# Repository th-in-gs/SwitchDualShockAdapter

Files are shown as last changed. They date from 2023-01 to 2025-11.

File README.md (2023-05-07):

# SwitchDualShockAdapter

A work-in-progress Dual Shock to Switch controller adapter using an ATMega8A and V-USB.

I'm documenting the project on my blog, https://www.blog.montgomerie.net/tags/switch-dual-shock-adapter-series/.

# Acknowledgements

This project is designed to be compiled by the PlatformIO system (https://platformio.org).

This project depends upon Objective Development's V-USB (https://www.obdev.at/vusb/) - see the `v-usb` directory.

This project depends upon the MiniCore implementation of the Arduino framework (https://github.com/MCUdude/MiniCore).

# Copyright

Copyright 2023 James Montgomerie.

This project is distributed under the terms of the GNU General Public License (see LICENSE.txt), in order to comply with the licensing conditions of its dependencies (see 'Acknowledgements').

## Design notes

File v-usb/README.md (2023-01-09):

What is V-USB?
==============
V-USB is a firmware-only USB driver for Atmel's AVR microcontrollers.
For more information please visit <http://www.obdev.at/vusb/>.

What is in this Repository?
===========================
This repository contains the source code of the driver (in the usbdrv
subdirectory), examples (in the examples) subdirectory and other things
you might need when you design a device using V-USB.

When you check out this repository, the resulting directory is *not* equivalent
to the source code package which can be downloaded at
<http://www.obdev.at/vusb/>. Some files in the source code package are generated
by scripts when the package is created. On the other hand, the scripts which
generate source files and the package are not contained in the package itself.

If you want to know more about the files and directories, see the file
Readme.txt in the top level directory.

How do I Add the Driver to My Project?
======================================
Simply copy the entire usbdrv subdirectory into your project's firmware
source code directory. Then edit the firmware's Makefile and add the following
object files to your binary:

    usbdrv/usbdrv.o
    usbdrv/usbdrvasm.o
    usbdrv/oddebug.o

Then make sure that your Makefile contains rules to convert *.S and *.c to
object files. See the Makefiles in the examples subdirectory for an
inspiration.

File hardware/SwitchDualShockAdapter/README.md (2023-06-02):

KiCad project, with schematic and PCB layout.
The PCB should be run through the "Round Tracks" plugin before production.
The components associated with the two LEDs are optional, as are one of either the USB header or USB-C port

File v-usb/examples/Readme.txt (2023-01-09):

This is the Readme file for the directory "examples" of V-USB, a firmware-
only USB driver for AVR microcontrollers.

WHAT IS IN THIS DIRECTORY?
==========================
This directory contains examples which are mostly for educational purposes.
Examples can be device firmware only, host software only or both. Here is
a summary:

custom-class
  A custom class device with host software based on libusb. It demonstrates
  the straight forward way of sending small amounts of data to a device and
  receiving data from the device. It does NOT demonstrate how to send large
  amounts of data to the device or how to receive data generated on the fly
  by the device (how to use usbFunctionWrite() and usbFunctionRead()). See
  the hid-data example for how usbFunctionWrite() and usbFunctionRead() are
  used.

hid-custom-rq
  This example implements the same functionality as the custom-class example
  above, but declares the device as HID. This prevents the "give me a driver
  CD" dialog on Windows. The device can still be controlled with libusb as in
  the previous example (on Windows, the filter version of libusb-win32 must
  be installed). In addition to the features presented in custom-class, this
  example demonstrates how a HID class device is defined.

hid-mouse
  This example implements a mouse device. No host driver is required since
  today's operating systems have drivers for USB mice built-in. It
  demonstrates how a real-world HID class device is implemented and how
  interrupt-in endpoints are used.

hid-data
  This example demonstrates how the HID class can be misused to transfer
  arbitrary data over HID feature reports. This technique is of great value
  on Windows because no driver DLLs are needed (the hid-custom-rq example
  still requires the libusb-win32 DLL, although it may be in the program's
  directory). The host side application requires no installation, it can
  even be started directly from a CD. This example also demonstrates how
  to transfer data using usbFunctionWrite() and usbFunctionRead().

usbtool
  This is a general purpose development and debugging tool for USB devices.
  You can use it during development of your device to test various requests
  without special test programs. But it is also an example how all the
  libusb API functions are used.

More information about each example can be found in the Readme file in the
respective directory.

Hardware dependencies of AVR code has been kept at a minimum. All examples
should work on any AVR chip which has enough resources to run the driver.
Makefile and usbconfig.h have been configured for the metaboard hardware (see
http://www.obdev.at/goto.php?t=metaboard for details). Edit the target
device, fuse values, clock rate and programmer in Makefile and the I/O pins
dedicated to USB in usbconfig.h.

WHAT IS NOT DEMONSTRATED IN THESE EXAMPLES?
===========================================
These examples show only the most basic functionality. More elaborate
examples and real world applications showing more features of the driver are
available at http://www.obdev.at/vusb/projects.html. Most of these
features are described in our documentation wiki at
http://www.obdev.at/goto.php?t=vusb-wiki.

To mention just a few:

Using RC oscillator for system clock
  The 12.8 MHz and 16.5 MHz modules of V-USB have been designed to cope
  with clock rate deviations up to 1%. This allows an RC oscillator to be
  used. Since the AVR's RC oscillator has a factory precision of only 10%,
  it must be calibrated to an external reference. The EasyLogger example
  shows how this can be done.

Dynamically generated descriptors
  Sometimes you want to implement different typtes of USB device depending
  on a jumper or other condition. V-USB has a very flexible interface for
  providing USB descriptors. See AVR-Doper for how to provide descriptors
  at runtime.

Virtual COM port
  Some people prefer a virtual serial interface to communicate with their
  device. We strongly discourage this method because it does things
  forbidden by the USB specification. If you still want to go this route,
  see AVR-CDC.

Implementing suspend mode
  V-USB does not implement suspend mode. This means that the device does
  not reduce power consumption when the host goes into sleep mode. Device
  firmware is free to implement suspend mode, though. See USB2LPT for an
  example.

The projects mentioned above can best be found on

    http://www.obdev.at/vusb/prjall.html

where all projects are listed.

----------------------------------------------------------------------------
(c) 2009 by OBJECTIVE DEVELOPMENT Software GmbH.
http://www.obdev.at/

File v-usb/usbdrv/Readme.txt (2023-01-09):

This is the Readme file to Objective Development's firmware-only USB driver
for Atmel AVR microcontrollers. For more information please visit
http://www.obdev.at/vusb/

This directory contains the USB firmware only. Copy it as-is to your own
project and add all .c and .S files to your project (these files are marked
with an asterisk in the list below). Then copy usbconfig-prototype.h as
usbconfig.h to your project and edit it according to your configuration.

TECHNICAL DOCUMENTATION
=======================
The technical documentation (API) for the firmware driver is contained in the
file "usbdrv.h". Please read all of it carefully! Configuration options are
documented in "usbconfig-prototype.h".

The driver consists of the following files:
  Readme.txt ............. The file you are currently reading.
  Changelog.txt .......... Release notes for all versions of the driver.
  usbdrv.h ............... Driver interface definitions and technical docs.
* usbdrv.c ............... High level language part of the driver. Link this
                           module to your code!
* usbdrvasm.S ............ Assembler part of the driver. This module is mostly
                           a stub and includes one of the usbdrvasm*.S files
                           depending on processor clock. Link this module to
                           your code!
  usbdrvasm*.inc ......... Assembler routines for particular clock frequencies.
                           Included by usbdrvasm.S, don't link it directly!
  asmcommon.inc .......... Common assembler routines. Included by
                           usbdrvasm*.inc, don't link it directly!
  usbconfig-prototype.h .. Prototype for your own usbdrv.h file.
* oddebug.c .............. Debug functions. Only used when DEBUG_LEVEL is
                           defined to a value greater than 0. Link this module
                           to your code!
  oddebug.h .............. Interface definitions of the debug module.
  usbportability.h ....... Header with compiler-dependent stuff.
  usbdrvasm.asm .......... Compatibility stub for IAR-C-compiler. Use this
                           module instead of usbdrvasm.S when you assembler
                           with IAR's tools.
  License.txt ............ Open Source license for this driver.
  CommercialLicense.txt .. Optional commercial license for this driver.
  USB-ID-FAQ.txt ......... General infos about USB Product- and Vendor-IDs.
  USB-IDs-for-free.txt ... List and terms of use for free shared PIDs.

(*) ... These files should be linked to your project.

CPU CORE CLOCK FREQUENCY
========================
We supply assembler modules for clock frequencies of 12 MHz, 12.8 MHz, 15 MHz,
16 MHz, 16.5 MHz 18 MHz and 20 MHz. Other clock rates are not supported. The
actual clock rate must be configured in usbconfig.h.

12 MHz Clock
This is the traditional clock rate of V-USB because it's the lowest clock
rate where the timing constraints of the USB spec can be met.

15 MHz Clock
Similar to 12 MHz, but some NOPs inserted. On the other hand, the higher clock
rate allows for some loops which make the resulting code size somewhat smaller
than the 12 MHz version.

16 MHz Clock
This clock rate has been added for users of the Arduino board and other
ready-made boards which come with a fixed 16 MHz crystal. It's also an option
if you need the slightly higher clock rate for performance reasons. Since
16 MHz is not divisible by the USB low speed bit clock of 1.5 MHz, the code
is somewhat tricky and has to insert a leap cycle every third byte.

12.8 MHz and 16.5 MHz Clock
The assembler modules for these clock rates differ from the other modules
because they have been built for an RC oscillator with only 1% precision. The
receiver code inserts leap cycles to compensate for clock deviations. 1% is
also the precision which can be achieved by calibrating the internal RC
oscillator of the AVR. Please note that only AVRs with internal 64 MHz PLL
oscillator can reach 16.5 MHz with the RC oscillator. This includes the very
popular ATTiny25, ATTiny45, ATTiny85 series as well as the ATTiny26. Almost
all AVRs can reach 12.8 MHz, although this is outside the specified range.

See the EasyLogger example at http://www.obdev.at/vusb/easylogger.html for
code which calibrates the RC oscillator based on the USB frame clock.

18 MHz Clock
This module is closer to the USB specification because it performs an on the
fly CRC check for incoming packets. Packets with invalid checksum are
discarded as required by the spec. If you also implement checks for data
PID toggling on application level (see option USB_CFG_CHECK_DATA_TOGGLING
in usbconfig.h for more info), this ensures data integrity. Due to the CRC
tables and alignment requirements, this code is bigger than modules for other
clock rates. To activate this module, you must define USB_CFG_CHECK_CRC to 1
and USB_CFG_CLOCK_KHZ to 18000 in usbconfig.h.

20 MHz Clock
This module is for people who won't do it with less than the maximum. Since
20 MHz is not divisible by the USB low speed bit clock of 1.5 MHz, the code
uses similar tricks as the 16 MHz module to insert leap cycles.

USB IDENTIFIERS
===============
Every USB device needs a vendor- and a product-identifier (VID and PID). VIDs
are obtained from usb.org for a price of 1,500 USD. Once you have a VID, you
can assign PIDs at will.

Since an entry level cost of 1,500 USD is too high for most small companies
and hobbyists, we provide some VID/PID pairs for free. See the file
USB-IDs-for-free.txt for details.

Objective Development also has some license offerings which include product
IDs. See http://www.obdev.at/vusb/ for details.

DEVELOPMENT SYSTEM
==================
This driver has been developed and optimized for the GNU compiler version 3
and 4. We recommend that you use the GNU compiler suite because it is freely
available. V-USB has also been ported to the IAR compiler and assembler. It
has been tested with IAR 4.10B/W32 and 4.12A/W32 on an ATmega8 with the
"small" and "tiny" memory model. Not every release is tested with IAR CC and
the driver may therefore fail to compile with IAR. Please note that gcc is
more efficient for usbdrv.c because this module has been deliberately
optimized for gcc.

Gcc version 3 produces smaller code than version 4 due to new optimizing
capabilities which don't always improve things on 8 bit CPUs. The code size
generated by gcc 4 can be reduced with the compiler options
-fno-move-loop-invariants, -fno-tree-scev-cprop and
-fno-inline-small-functions in addition to -Os. On devices with more than
8k of flash memory, we also recommend the linker option --relax (written as
-Wl,--relax for gcc) to convert absolute calls into relative where possible.

For more information about optimizing options see:

    http://www.tty1.net/blog/2008-04-29-avr-gcc-optimisations_en.html

These optimizations are good for gcc 4.x. Version 3.x of gcc does not support
most of these options and produces good code anyway.

USING V-USB FOR FREE
====================
The AVR firmware driver is published under the GNU General Public License
Version 2 (GPL2) and the GNU General Public License Version 3 (GPL3). It is
your choice whether you apply the terms of version 2 or version 3.

If you decide for the free GPL2 or GPL3, we STRONGLY ENCOURAGE you to do the
following things IN ADDITION to the obligations from the GPL:

(1) Publish your entire project on a web site and drop us a note with the URL.
Use the form at http://www.obdev.at/vusb/feedback.html for your submission.
If you don't have a web site, you can publish the project in obdev's
documentation wiki at
http://www.obdev.at/goto.php?t=vusb-wiki&p=hosted-projects.

(2) Adhere to minimum publication standards. Please include AT LEAST:
    - a circuit diagram in PDF, PNG or GIF format
    - full source code for the host software
    - a Readme.txt file in ASCII format which describes the purpose of the
      project and what can be found in which directories and which files
    - a reference to http://www.obdev.at/vusb/

(3) If you improve the driver firmware itself, please give us a free license
to your modifications for our commercial license offerings.

COMMERCIAL LICENSES FOR V-USB
=============================
If you don't want to publish your source code under the terms of the GPL,
you can simply pay money for V-USB. As an additional benefit you get
USB PIDs for free, reserved exclusively to you. See the file
"CommercialLicense.txt" for details.

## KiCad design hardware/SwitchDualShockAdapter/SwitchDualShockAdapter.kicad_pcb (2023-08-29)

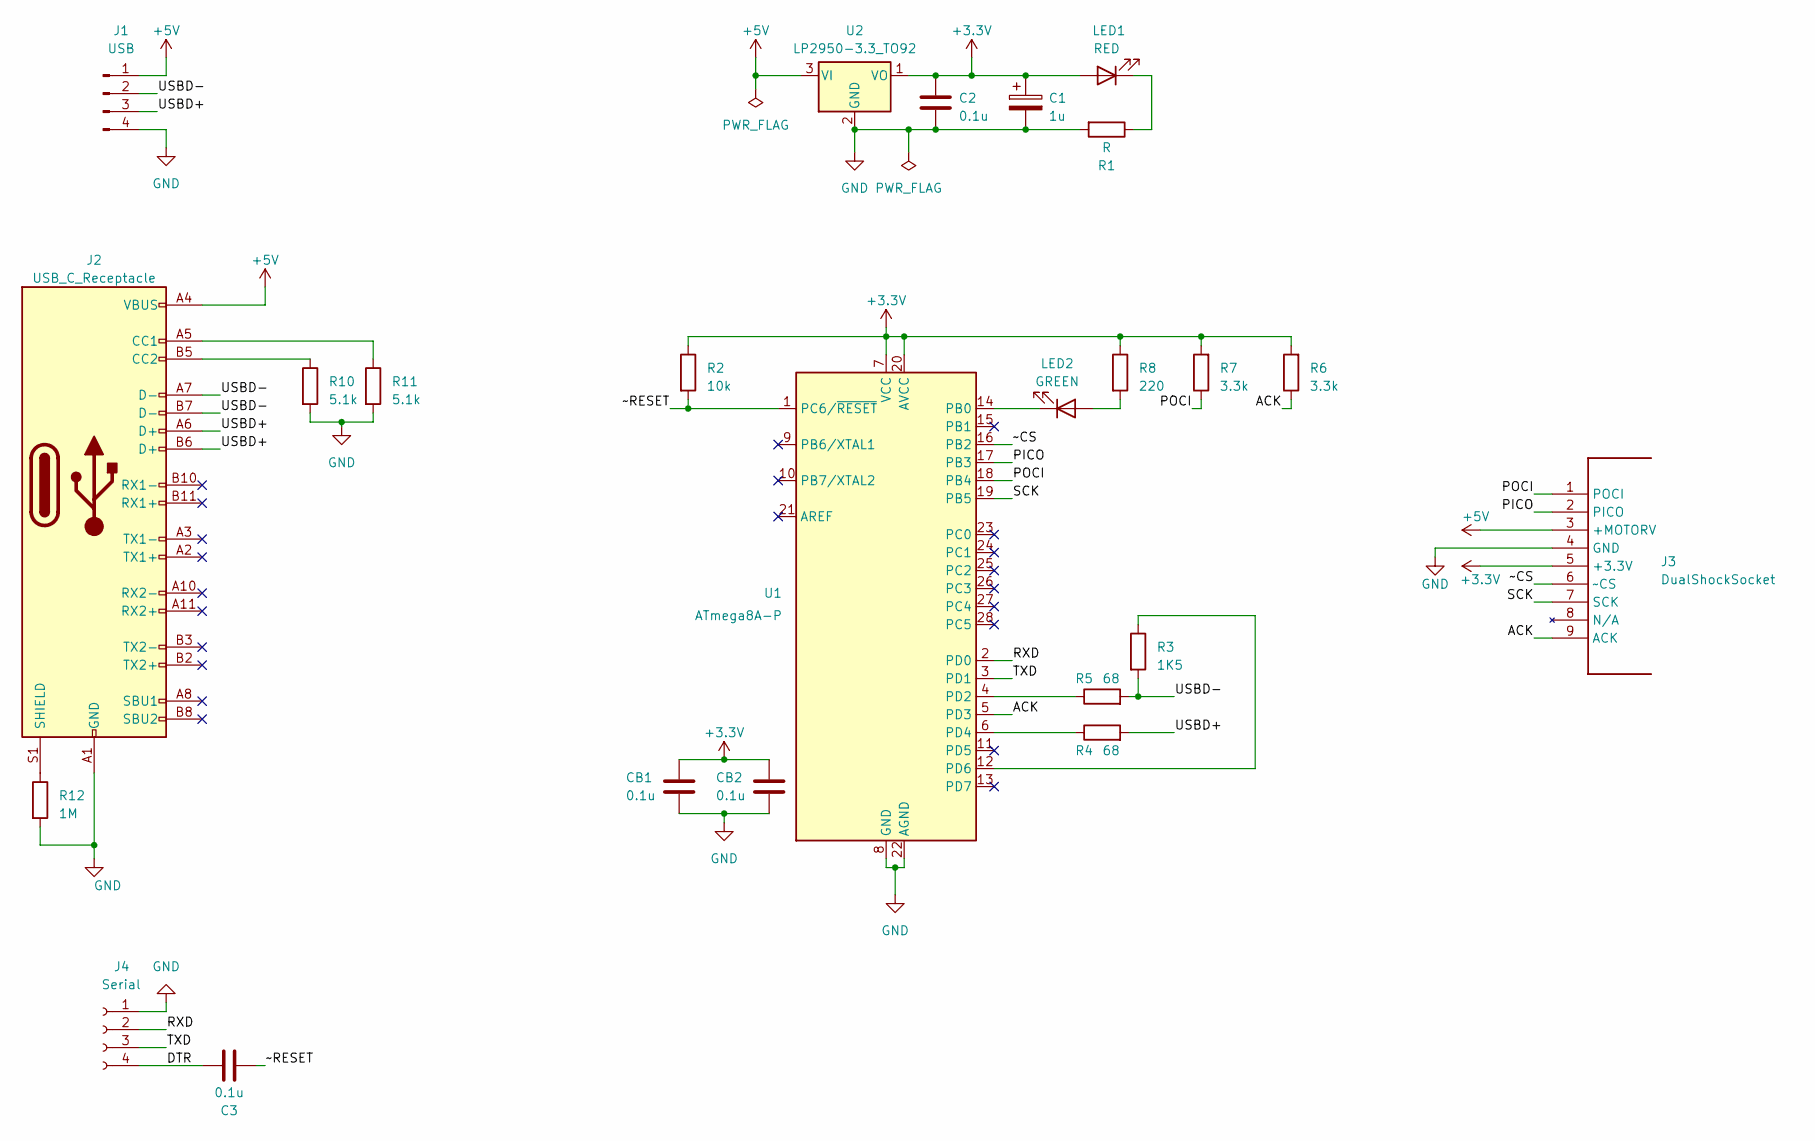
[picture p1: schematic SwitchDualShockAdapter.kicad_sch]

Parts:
C1: 1u; CP_Radial_D5.0mm_P2.00mm
C2, C3: 0.1u; C_Disc_D5.0mm_W2.5mm_P2.50mm
CB1, CB2: 0.1u; C_Disc_D5.0mm_W2.5mm_P2.50mm
J1: USB; PinHeader_1x04_P2.54mm_Vertical
J2: USB_C_Receptacle; TYPE-C-31-M-04
J3: DualShockSocket
J4: Serial; PinSocket_1x04_P2.54mm_Vertical
LED1: RED; LED_D5.0mm
LED2: GREEN; LED_D5.0mm
R1: R; R_Axial_DIN0207_L6.3mm_D2.5mm_P7.62mm_Horizontal
R2: 10k; R_Axial_DIN0207_L6.3mm_D2.5mm_P7.62mm_Horizontal
R3: 1K5; R_Axial_DIN0207_L6.3mm_D2.5mm_P7.62mm_Horizontal
R4, R5: 68; R_Axial_DIN0207_L6.3mm_D2.5mm_P7.62mm_Horizontal
R6, R7: 3.3k; R_Axial_DIN0207_L6.3mm_D2.5mm_P7.62mm_Horizontal
R8: 220; R_Axial_DIN0207_L6.3mm_D2.5mm_P7.62mm_Horizontal
R10, R11: 5.1k; R_Axial_DIN0207_L6.3mm_D2.5mm_P7.62mm_Horizontal
R12: 1M; R_Axial_DIN0207_L6.3mm_D2.5mm_P7.62mm_Horizontal
U1: ATmega8A-P; DIP-28_W7.62mm
U2: LP2950-3.3_TO92; TO-92_Inline

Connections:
+3.3V: C1.1, C2.1, CB1.1, CB2.1, J3.5 (+3.3V), LED1.2 (A), R2.1, R6.2, R7.2, R8.1, U1.7 (VCC), U1.20 (AVCC), U2.1 (VO)
+5V: J1.1, J2.A4 (VBUS), J2.A9 (VBUS), J2.B4 (VBUS), J2.B9 (VBUS), J3.3 (+MOTORV), U2.3 (VI)
/ACK: J3.9 (ACK), R6.1, U1.5 (PD3)
/DTR: C3.2, J4.4
/PICO: J3.2 (PICO), U1.17 (PB3)
/POCI: J3.1 (POCI), R7.1, U1.18 (PB4)
/RXD: J4.2, U1.2 (PD0)
/SCK: J3.7 (SCK), U1.19 (PB5)
/TXD: J4.3, U1.3 (PD1)
/USBD+: J1.3, J2.A6 (D+), J2.B6 (D+), R4.2
/USBD-: J1.2, J2.A7 (D-), J2.B7 (D-), R3.2, R5.2
/~CS: J3.6 (~CS), U1.16 (PB2)
/~RESET: C3.1, R2.2, U1.1 (PC6/~RESET)
GND: C1.2, C2.2, CB1.2, CB2.2, J1.4, J2.A1 (GND), J2.A12 (GND), J2.B1 (GND), J2.B12 (GND), J3.4 (GND), J4.1, R1.2, R10.2, R11.2, R12.2, U1.8 (GND), U1.22 (AGND), U2.2 (GND)
unnamed: J2.A5 (CC1), R11.1
unnamed: J2.B5 (CC2), R10.1
unnamed: J2.31, J2.32, J2.S1 (SHIELD), R12.1
unnamed: LED1.1 (K), R1.1
unnamed: LED2.2 (A), R8.2
unnamed: LED2.1 (K), U1.14 (PB0)
unnamed: R5.1, U1.4 (PD2)
unnamed: R4.1, U1.6 (PD4)
unnamed: R3.1, U1.12 (PD6)

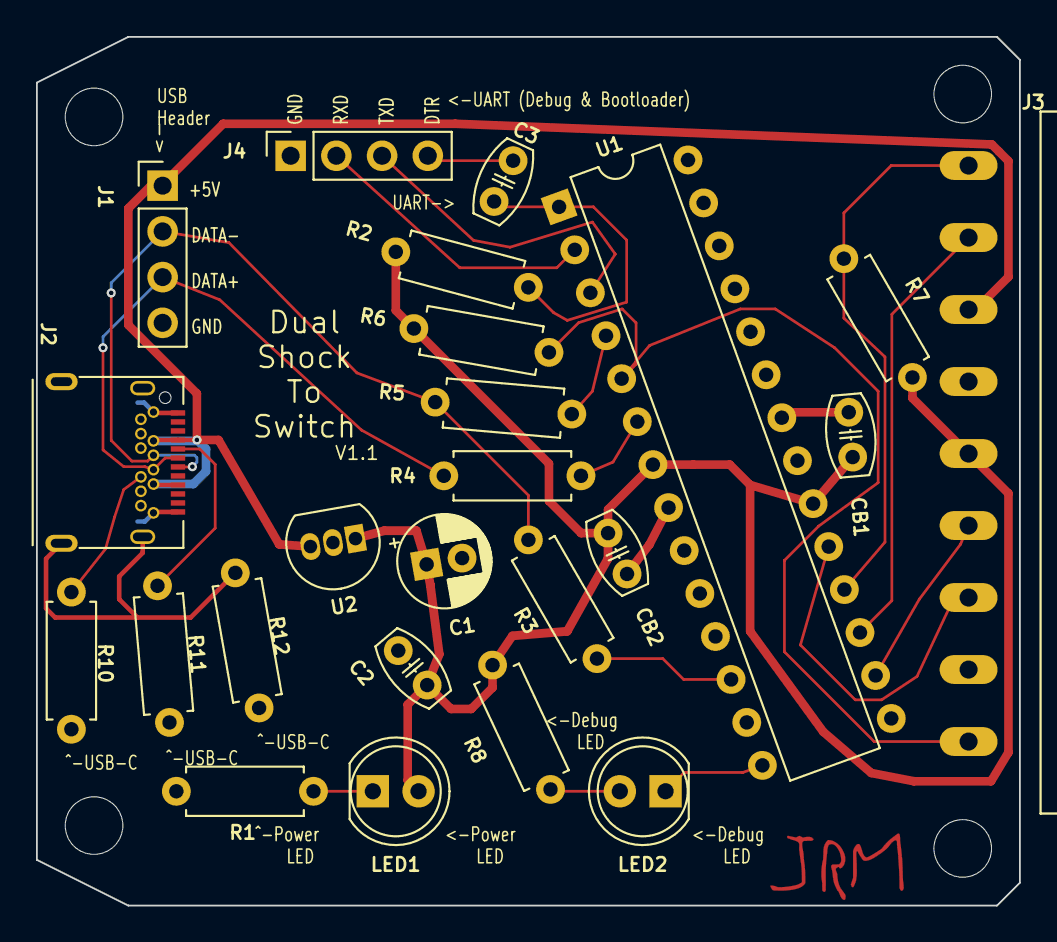
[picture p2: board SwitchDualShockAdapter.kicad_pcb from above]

Board: 2 copper layers, 54.6 x 48.3 mm, 24 parts (0 on the bottom side), 23 nets.

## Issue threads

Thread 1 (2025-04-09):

Multiple adapters

finger563, 2025-04-09:
Thanks for the blogs and the work you've done!

I've made something similar [here](https://github.com/finger563/esp-usb-ble-hid), and I'm trying to make it work for multiple controllers. Right now if I have two dongles, they each work independently, but as soon as the second is plugged in the first stops working with the switch.

I wasn't sure if this is something you've tested and if you had any information about what commands I might need to handle to allow this to work properly. I can have my dongle and a real switch pro controller both connected via USB, but I cannot have two of my dongles connected and both working via USB simultaneously :(

th-in-gs, 2025-04-10:
Thanks for filing this! Is yours reliable after just the MAC change?I had a similar problem when we tried to play Mario Kart with two PS1 controllers recently. I also needed to change the MAC for each controller. I haven’t updated the repo yet, because that still wasn’t quite reliable (and we started playing Mario Kart…). One controller (at random) _usually_ still didn’t work - but if both _started_ working, they both stayed working until the system slept or one was unplugged. Glad you found some value in my work!On Apr 10, 2025, at 09:12, William Emfinger ***@***.***> wrote:
  Nevermind, I figured it out! The mac address reported in the device info (on init and via command) needs to be unique between the devices, so I'm now using the chip's mac address and it works just fine :)—Reply to this email directly, view it on GitHub, or unsubscribe.You are receiving this because you are subscribed to this thread.Message ID: ***@***.***>

finger563 left a comment (th-in-gs/SwitchDualShockAdapter#1)
Nevermind, I figured it out! The mac address reported in the device info (on init and via command) needs to be unique between the devices, so I'm now using the chip's mac address and it works just fine :)

—Reply to this email directly, view it on GitHub, or unsubscribe.You are receiving this because you are subscribed to this thread.Message ID: ***@***.***>

finger563, 2025-04-12:
Yea I changed it so that the ESP32's MAC address is used both for the on-usb-attach device info read, as well as the SPI ROM read and additional device info read commands. After that, they've been very reliable and we've been able to play Ultimate with multiple controllers :)

Closed 2025-04-10.

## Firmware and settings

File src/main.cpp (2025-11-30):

#include "serial.h"
#include "timer.h"
#include "spiMemory.h"
#include "packedStrings.h"

#include "descriptors.h"
#include "rumble.h"
#include "compile_time_mac.h"

#include <stdlib.h>
#include <stddef.h>
#include <stdarg.h>
#include <stdint.h>
#include <string.h>
#include <stddef.h>

#include <avr/pgmspace.h>
#include <avr/eeprom.h>
#include <avr/interrupt.h>
#include <avr/sleep.h>
#include <util/delay.h>

extern "C" {
    #include <usbdrv/usbdrv.h>

    // We declare this to be used by V-USB's 'osccal.h' oscilator calibration
    // routine.
    uint8_t lastTimer0Value = 0;

    void usbFunctionRxHook(const uchar *data, const uchar len);
}

#define EEPROM_MAGIC 0x0007
void prepareEEPROM()
{
    static uint16_t * const lastInt16 = ((uint16_t *)E2END) - 1;
    uint16_t serial = eeprom_read_word(lastInt16);
    if(serial != EEPROM_MAGIC) {
        debugPrintStr6(STR6("EEPROM\n"));
        for(uint16_t *cursor = 0; cursor < lastInt16; ++cursor) {
            eeprom_update_word(cursor, 0xffff);
        }
        eeprom_update_word(lastInt16, EEPROM_MAGIC);
        //debugPrintStr6(STR6("Cleared\n"));
    }
}

void setup()
{
    // The oscilator is calibrated to 12.8MHz based on 1ms timing of USB frames
    // by the routines in osctune.h. This seems to be around where things
    // settle, so let's give ourselves a head start on reaching equilibrium
    // by starting here.
    // As well as helping USB communication to start up faster, this also helps
    // to get serial debug output working earlier.

#if __AVR_ATmega8__
    OSCCAL = 240;
#else
    OSCCAL = 226;
#endif

    // Set up sleep mode. This doesn't actually put the device to sleep yet -
    // It just sets the mode that will be used when `sleep_cpu()` is called.
    set_sleep_mode(SLEEP_MODE_PWR_DOWN);
    sleep_enable();

    // Initialize our utility functions.
    timerInit();
    serialInit(266667);

    prepareEEPROM();

    // Set port 2 outputs. Most of these pins are prescribed by the ATmega's
    // built in SPI communication hardware.
    DDRB |=
        1 << 5 | // SCK (PB5) - Serial data clock.
        1 << 3 | // PICO (PB3) - Serial data from ATmega to controller.
        1 << 2 | // Use PB2 for the controller's 'Chip Select' line
        1 << 0   // PB0 for our blinking debug LED.
    ;

    // Set up the SPI Control Register. Form right to left:
    // SPIE = 0 (SPI interrupt disabled - we'll just poll)
    // SPE  = 1 (SPI enabled)
    // DORD = 1 (Data order: LSB of the data word is transmitted first)
    // MSTR = 1 (Controller/Peripheral Select: Controller mode)
    // CPOL = 1 (Clock Polarity: Leading edge = falling)
    // CPHA = 1 (Clock Phase: Leading edge = setup, trailing ecdge = sample)
    // SPR1 SPR0 = 10 (Serial clock rate: 10 means (F_CPU / 64) -
    //                 so: (12.8MHz / 64) = 200kHz - but we'll double that below).
    SPCR = 0b01111110;

    // Double the SPI rate defined above (so 200kHz * 2 = 400kHz)
    SPSR |= 1 << SPI2X;

    // Need to set the controller's 'Chip Select', which is active-low, to high
    // so we can pull it low for each transaction.
    // PICO and SCK should rest at high too.
    // Also set the debug LED pin high (which will switch it off).
    PORTB |= 1 << 5 | 1 << 3 | 1 << 2 | 1 << 0;

    // Set up Interrupt 1 to fire when the the Dual Shock 'Acknowledge' line
    // goes low.
#if __AVR_ATmega8__
    MCUCR |= 1 << ISC11 | 1 << ISC10;
    GICR |= 1 << INT1;
#else
    EICRA |= 1 << ISC11 | 1 << ISC10;
    EIMSK |= 1 << INT1;
#endif

    // Disable interrupts for USB reset.
    cli();

    // Initialize V-USB.
    usbInit();

    // V-USB wiki (http://vusb.wikidot.com/driver-api) says:
    //      "In theory, you don't need this, but it prevents inconsistencies
    //      between host and device after hardware or watchdog resets."
    usbDeviceDisconnect();
    _delay_ms(250);
    usbDeviceConnect();

    // Enable interrupts again.
    sei();
}

static const uint8_t sReportSize = 64;

static uint8_t sReports[2][sReportSize];
static uint8_t sReportsInputReportPosition[2] = { 0 };
static uint8_t sReportLengths[2] = { 0 };
static uint8_t sCurrentReport = 0;
static bool sReportPending = false;

static bool sInputReportsSuspended = false;

static const uint8_t sCommandHistoryLength = 32;
static uint8_t sCommandHistory[sCommandHistoryLength][3] = {0};
static uint8_t sCommandHistoryCursor = 0;

static bool sRumbleEnabled = false;
static uint8_t sLowRumbleAmplitude = 0;
static uint8_t sHighRumbleAmplitude = 0;

static void haltStr6(uint8_t i, const uint8_t *messageStr6 = NULL)
{
    serialPrintStr6(STR6("HALT: 0x"), true);
    serialPrintHex(i, true);
    if(messageStr6) {
        serialPrint(' ', true);
        serialPrintStr6(messageStr6, true);
    }
    serialPrint('\n', true);
    for(uint8_t i = 0; i < sCommandHistoryLength; ++i) {
        serialPrint('\t', true);
        serialPrintHex(sCommandHistory[sCommandHistoryCursor][0], true);
        serialPrint(',', true);
        serialPrintHex(sCommandHistory[sCommandHistoryCursor][1], true);
        serialPrint(',', true);
        serialPrintHex(sCommandHistory[sCommandHistoryCursor][2], true);
        serialPrint('\n', true);
        if(sCommandHistoryCursor == 0) {
            sCommandHistoryCursor = sCommandHistoryLength - 1;
        } else {
            --sCommandHistoryCursor;
        }
    }

    while(true);
}

// The Dual Shock's ACK line is connected to pin 5, INT1.
static volatile bool sDualShockAcknowledgeReceived = false;
ISR(INT1_vect, ISR_NOBLOCK)
{
    // Set the flag so that the main code can know about the acknowledgement.
    sDualShockAcknowledgeReceived = true;
}

static uint8_t dualShockCommand(const uint8_t *command, const uint8_t commandLength,
    uint8_t *toReceive, const uint8_t toReceiveLength)
{
    // Pull-down the ~CS ('Attention') line.
    PORTB &= ~(1 << 2);

    // Give the controller a little time to notice (this seems to be necessary
    // for reliable communication).
    _delay_us(20);

    // Loop using SPI hardware to send/receive each byte in the command.
    uint8_t byteIndex = 0;
    uint8_t reportedTransactionLength = 2;
    bool byteAcknowledged = false;
    bool errored = false;
    do {
        // This will be set to true by the interrupt routine, above,
        // when the Dual Shock sends its acknowledge signal.
        sDualShockAcknowledgeReceived = false;

        // Put what we want to send into the SPI Data Register.
        if(byteIndex == 0) {
            // All transactions start with a 1 byte.
            SPDR = 0x01;
        } else if(byteIndex <= commandLength) {
            // If we still have [part of] a command to transmit.
            SPDR = command[byteIndex - 1];
        } else {
            // Otherwise, pad with 0s like a PS1 would.
            SPDR = 0x00;
        }

        // Wait for the SPI hardware do its thing:
        // Loop until SPIF, the SPI Interrupt Flag in the SPI State Register,
        // is set, signifying the SPI transaction is complete.
        while(!(SPSR & (1 << SPIF)));

        // Grab the received byte from the SPI Data register.
        // This has the side-effect of clearing the SPIF flag (see above).
        const uint8_t received = SPDR;

        // Process what we've received.
        if(byteIndex == 1) {
            // The byte in position 1 contains the length to expect _after
            // the header_ in its lower nybble.
            reportedTransactionLength = ((received & 0xf) * 2) + 3;
        } else if(byteIndex == 2) {
            // Online docs suggest this is _always_ 0x5a, but in reality it's
            // 0x00 after the 'ANALOG' button has been pressed (unfortunately
            // not _while_ it's being pressed).
            if(received != 0x5a && received != 0x00) {
                    errored = true;
                    break;
            }
        }

        if(byteIndex < toReceiveLength) {
            // Store the byte in the buffer we were passed, if there's room.
            toReceive[byteIndex] = received;
        }

        ++byteIndex;

        byteAcknowledged = sDualShockAcknowledgeReceived;

        // Wait for the Dual Shock to acknowledge the byte.
        // All bytes except the last one(?!) are acknowledged.
        if(byteIndex < reportedTransactionLength) {
            uint8_t microsWaited = 0;
            while(!byteAcknowledged) {
                if(microsWaited > 100) {
                    // Sometimes, especially when it's in command mode, the Dual
                    // Shock seems to get into a bad state and 'give up'.
                    // Detect this and bail.
                    // We'll return failure from this function, and it's up to
                    // the caller to try again if they want to.
                    errored = true;
                    break;
                }
                _delay_us(2);
                microsWaited += 2;
                byteAcknowledged = sDualShockAcknowledgeReceived;
            }
        }
    } while(!errored && byteIndex < reportedTransactionLength);

    // Despite the fact that the controller doens't raise the acknowledge line
    // for the last byte, we still seem to need to wait a bit for communication
    // to be reliable :-|.
    _delay_us(20);

    // ~CS line ('Attention') needs to be raised to its inactive state between
    // each transaction.
    PORTB |= 1 << 2;

    return errored ? 0 : byteIndex;
}

static uint16_t eightBitToTwelveBit(const uint16_t eightBit)
{
#if 0
    // We replicate the high 4 bits into the bottom 4 bits of the
    // Switch report, so that e.g. 0xFF maps to 0XFFF and 0x00 maps to 0x000
    // The mid-point of 0x80 maps to 0x808, which is a bit off - but
    // 0x80 is in fact off too: the real midpoint of [0x00 - 0xff] is 0x7f.8
    // (using a hexadecimal point there, like a decimal point).

    return (eightBit << 4) | (eightBit >> 4);
#else
    // We actually have plenty of time and space to calculate this accurately
    // without the bit-shifting tricks above.
    uint32_t builder = (uint32_t)eightBit * (uint32_t)0xfff;
    uint16_t twelveBit = builder / (uint32_t)0xff;
    return twelveBit;
#endif
}

// Weird extern declaration to keep VS Code happy. It's not actually necessary
// for compilation, but Intellisense can't find a declaration when editing
extern uint8_t (__builtin_avr_insert_bits)(uint32_t, uint8_t, uint8_t);

static void convertDualShockToSwitch(const DualShockReport *dualShockReport, SwitchReport *switchReport)
{
    memset(switchReport, 0, sizeof(SwitchReport));

    // Fake values.
    switchReport->connectionInfo = 0x1;
    switchReport->batteryLevel = 0x8;

    // Dual Shock buttons are 'active low' (0 = on, 1 = off), so we need to
    // invert their value before assigning to the Switch report.

    uint8_t dualShockButtons1 = ~dualShockReport->buttons1;
    uint8_t dualShockButtons2 = ~dualShockReport->buttons2;

    // Use GCC bit insertion intrinsics to do the same as the commented out
    // code below (more efficient - but really to save code space)
    switchReport->buttons1 = __builtin_avr_insert_bits(0x13ff5647, dualShockButtons2, 0);
    switchReport->buttons2 = __builtin_avr_insert_bits(0xffff1230, dualShockButtons1, 0);
    switchReport->buttons3 = __builtin_avr_insert_bits(0x02ffffff, dualShockButtons2, 0);
    switchReport->buttons3 = __builtin_avr_insert_bits(0xffff7546, dualShockButtons1, switchReport->buttons3);

/*
    switchReport->yButton = !dualShockReport->squareButton;
    switchReport->xButton = !dualShockReport->triangleButton;
    switchReport->bButton = !dualShockReport->crossButton;
    switchReport->aButton = !dualShockReport->circleButton;
    switchReport->rShoulderButton = !dualShockReport->r1Button;
    switchReport->zRShoulderButton = !dualShockReport->r2Button;

    switchReport->minusButton = !dualShockReport->selectButton;
    switchReport->plusButton = !dualShockReport->startButton;
    switchReport->rStickButton = !dualShockReport->r3Button;
    switchReport->lStickButton = !dualShockReport->l3Button;

    switchReport->downButton = !dualShockReport->downButton;
    switchReport->upButton = !dualShockReport->upButton;
    switchReport->rightButton = !dualShockReport->rightButton;
    switchReport->leftButton = !dualShockReport->leftButton;
    switchReport->lShoulderButton = !dualShockReport->l1Button;
    switchReport->zLShoulderButton = !dualShockReport->l2Button;
*/

    // The Switch has 12-bit analog sticks. The Dual Shock has 8-bit.
    //
    // Byte (nybble?) order of the values here strikes me as a bit weird.
    // If the three bytes (with two nybbles each) are AB CD EF,
    // the decoded 12-bit values are DAB, EFC. It makes more sense 'backwards'?

    uint8_t leftStickX = dualShockReport->leftStickX;
    uint16_t leftStickX12 = eightBitToTwelveBit(leftStickX);
    uint8_t leftStickY = 0xff - dualShockReport->leftStickY;
    uint16_t leftStickY12 = eightBitToTwelveBit(leftStickY);
    switchReport->leftStick[2] = leftStickY12 >> 4;
    switchReport->leftStick[1] = (leftStickY12 << 4) | (leftStickX12 >> 8);
    switchReport->leftStick[0] = leftStickX12 & 0xff;

    uint8_t rightStickX = dualShockReport->rightStickX;
    uint16_t rightStickX12 = eightBitToTwelveBit(rightStickX);
    uint8_t rightStickY = 0xff - dualShockReport->rightStickY;
    uint16_t rightStickY12 = eightBitToTwelveBit(rightStickY);
    switchReport->rightStick[2] = rightStickY12 >> 4;
    switchReport->rightStick[1] = (rightStickY12 << 4) | (rightStickX12 >> 8);
    switchReport->rightStick[0] = rightStickX12 & 0xff;
}

static void prepareInputSubReportInBuffer(uint8_t *buffer)
{
    SwitchReport *switchReport = (SwitchReport *)buffer;

    struct DualShockCommand {
        const uint8_t length;
        const uint8_t commandSequence[];
    };

    // second-to-last and last byte are small motor (on/off?),
    // large motor (~0x40-0xff?)
    static const PROGMEM DualShockCommand pollCommand[] = { { 2, { 0x42, 0x00 } } };
    static const PROGMEM DualShockCommand enterConfigCommand[] = { { 3, { 0x43, 0x00, 0x01 } } };
    static const PROGMEM DualShockCommand exitConfigCommand[] = { { 3, { 0x43, 0x00, 0x00 } } };
    static const PROGMEM DualShockCommand switchToAnalogCommand[] = { { 3, { 0x44, 0x00, 0x01 } } };
    static const PROGMEM DualShockCommand setUpMotorsCommand[] = { { 8, { 0x4D, 0x00, 0x00, 0x01, 0xFF, 0xFF, 0xFF, 0xFF } } };

    static const PROGMEM DualShockCommand *const enterAnalogCommandSequence[] = {
        enterConfigCommand,
        switchToAnalogCommand,
        setUpMotorsCommand,
        exitConfigCommand,
    };

    static DualShockReport dualShockReports[2] = { EMPTY_DUAL_SHOCK_REPORT, EMPTY_DUAL_SHOCK_REPORT };
    static uint8_t previousDualShockReportIndex = 0;

    static const DualShockCommand * const *commandQueue;
    static uint8_t commandQueueCursor = 0;
    static uint8_t commandQueueLength = 0;

    static bool analogButtonIsPressed = false;
    static uint8_t analogButtonPressSofCount = 0;

    uint8_t replyLength = 0;
    uint8_t thisDualShockReportIndex = (uint8_t)(previousDualShockReportIndex + 1) % 2;

    const bool executingCommandQueue = (commandQueueCursor < commandQueueLength);
    const DualShockCommand *commandToExecute_P;

    if(!executingCommandQueue) {
        // If there's no command queue (the usual case), we just poll
        // controller state.
        commandToExecute_P = pollCommand;
    } else {
        commandToExecute_P = (DualShockCommand *)pgm_read_ptr(commandQueue + commandQueueCursor);
    }

    uint8_t commandLength = pgm_read_byte((uint8_t *)commandToExecute_P + offsetof(DualShockCommand, length));
    uint8_t command[commandLength + 4];
    memcpy_P(&command, commandToExecute_P + offsetof(DualShockCommand, commandSequence), commandLength);

    // Ick to this special-casing...
    if(commandToExecute_P == pollCommand && sRumbleEnabled) {
        const uint8_t lowRumbleAmplitude = sLowRumbleAmplitude ?: sHighRumbleAmplitude;
        const uint8_t highRumbleAmplitude = sHighRumbleAmplitude ?: sLowRumbleAmplitude;

        bool highRumbleOn = false;
        if(highRumbleAmplitude) {
            // The small motor is only either on or off, so we do some crude
            // PWM here to simulate the amplitude.
            static uint8_t activationCount = 0;
            const uint8_t duty_cycle = 0x0f / (highRumbleAmplitude >> 4);
            activationCount = (activationCount + 1) % duty_cycle;
            highRumbleOn = (activationCount == 0);
        }

        commandLength += 2;
        command[2] = highRumbleOn ? 0xff : 0; // Small motor. On = 0xff, Off = anything else. High
        command[3] = lowRumbleAmplitude; // Big motor. Practical range is 0x40 - 0xff. Low
    }

    replyLength = dualShockCommand(command,
                                   commandLength,
                                   (uint8_t *)&dualShockReports[thisDualShockReportIndex],
                                   sizeof(DualShockReport));

    if(!executingCommandQueue) {
        if(replyLength >= 2) {
            const uint8_t mode = dualShockReports[thisDualShockReportIndex].deviceMode;

            if(mode != 0x7) {
                // If we're _not_ in analog mode, initiate the sequence of
                // commands that will cause the controller to switch to analog
                // mode. One command is performed every time this function
                // is called.
                commandQueue = enterAnalogCommandSequence;
                commandQueueCursor = 0;
                commandQueueLength = 4;

                if(mode == 0x4) {
                    // If we're in digital  mode, it means the user pressed the
                    // analog button. We treat this as a home button press.
                    // Because we can't get any information about when the
                    // button is _released_, we record the time (in USB
                    // 1ms SOFs) when the press ocurred and switch it on
                    // for a few ms (see below).
                    analogButtonIsPressed = true;
                    analogButtonPressSofCount = usbSofCount;
                }
            }
        }
    } else {
        if(replyLength >= 2 && dualShockReports[thisDualShockReportIndex].deviceMode == 0xF) {
            // On to the next command!
            ++commandQueueCursor;
        } else {
            // The dual shock seems prome to failure to enter comamnd mode,
            // and to execute commands. If something's gone wrong, just
            // start the queue again.
            commandQueueCursor = 0;
        }
    }

    if(replyLength != sizeof(DualShockReport) || dualShockReports[thisDualShockReportIndex].deviceMode != 0x7) {
        // Not an analog report. We'll just use the previous one until the
        // controller gets back into a good state.
        thisDualShockReportIndex = previousDualShockReportIndex;
    }

    convertDualShockToSwitch(&dualShockReports[thisDualShockReportIndex], switchReport);

    if(analogButtonIsPressed) {
        if((uint8_t)(usbSofCount - analogButtonPressSofCount) < 64) {
            // Because we don't get any information about when the analog button
            // is _released_ (see above) we use the 1ms USB SOF count to pretend
            // the home button was pressed for a few ms.
            switchReport->homeButton = 1;
        } else {
            analogButtonIsPressed = false;
        }
    }

    previousDualShockReportIndex = thisDualShockReportIndex;
}

static void prepareInputReport()
{
    uint8_t *report = sReports[sCurrentReport];
    report[0] = 0x30;
    report[1] = usbSofCount; // This is meant to be an increasing timestamp - the SOF count is just a handy available 1ms counter.

    sReportsInputReportPosition[sCurrentReport] = 2;
    sReportLengths[sCurrentReport] = 2 + sizeof(SwitchReport);
    sReportPending = true;
}

static void prepareRegularReplyReport_P(uint8_t reportId, uint8_t reportCommand, const uint8_t *reportIn, uint8_t reportInLen)
{
    if(sReportPending) {
        haltStr6(0, STR6("Report Clash"));
        return;
    }

    uint8_t *report = sReports[sCurrentReport];
    report[0] = reportId;
    report[1] = reportCommand;
    memcpy_P(&report[2], reportIn, reportInLen);

    sReportLengths[sCurrentReport] = 2 + reportInLen;
    sReportPending = true;
}

static void prepareUartReplyReport_F(uint8_t ack, uint8_t subCommand, const uint8_t *reportIn, uint8_t reportInLen,  void *(*copyFunction)(void *, const void *, size_t))
{
    // '_F' - means pass in function to use for memcpying.

    if(sReportPending) {
        haltStr6(0, STR6("Report Clash"));
        return;
    }

    uint8_t reportLength = 0;
    uint8_t *report = sReports[sCurrentReport];
    report[reportLength++] = 0x21;
    report[reportLength++] = usbSofCount;

    sReportsInputReportPosition[sCurrentReport] = reportLength;
    reportLength += sizeof(SwitchReport);

    report[reportLength++] = ack;
    report[reportLength++] = subCommand;

    if(reportInLen == 0) {
        report[reportLength++] = 0x00;
    } else {
        const uint8_t reportSizeBeforeCopy = reportLength;
        reportLength += reportInLen;
        if(reportLength > sReportSize) {
            haltStr6(0, STR6("Report Too Big"));
            return;
        }
        copyFunction(&report[reportSizeBeforeCopy], reportIn, reportInLen);
    }

    sReportLengths[sCurrentReport] = reportLength;
    sReportPending = true;
}

static void prepareUartReplyReport_P(uint8_t ack, uint8_t subCommand, const uint8_t *reportIn, uint8_t reportInLen)
{
    return prepareUartReplyReport_F(ack, subCommand, reportIn, reportInLen, memcpy_P);
}
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
int main() {
    setup();
    do {
        loop();
    } while(true);
}

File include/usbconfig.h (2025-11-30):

/* Name: usbconfig.h
 * Project: V-USB, virtual USB port for Atmel's(r) AVR(r) microcontrollers
 * Author: Christian Starkjohann
 * Creation Date: 2005-04-01
 * Tabsize: 4
 * Copyright: (c) 2005 by OBJECTIVE DEVELOPMENT Software GmbH
 * License: GNU GPL v2 (see License.txt), GNU GPL v3 or proprietary (CommercialLicense.txt)
 */

#ifndef __usbconfig_h_included__
#define __usbconfig_h_included__

/*
General Description:
This file is an example configuration (with inline documentation) for the USB
driver. It configures V-USB for USB D+ connected to Port D bit 2 (which is
also hardware interrupt 0 on many devices) and USB D- to Port D bit 4. You may
wire the lines to any other port, as long as D+ is also wired to INT0 (or any
other hardware interrupt, as long as it is the highest level interrupt, see
section at the end of this file).
+ To create your own usbconfig.h file, copy this file to your project's
+ firmware source directory) and rename it to "usbconfig.h".
+ Then edit it accordingly.
*/

/* ---------------------------- Hardware Config ---------------------------- */

#define USB_CFG_IOPORTNAME      D
/* This is the port where the USB bus is connected. When you configure it to
 * "B", the registers PORTB, PINB and DDRB will be used.
 */
#define USB_CFG_DMINUS_BIT      2
/* This is the bit number in USB_CFG_IOPORT where the USB D- line is connected.
 * This may be any bit in the port.
 */
#define USB_CFG_DPLUS_BIT       4
/* This is the bit number in USB_CFG_IOPORT where the USB D+ line is connected.
 * This may be any bit in the port. Please note that D+ must also be connected
 * to interrupt pin INT0! [You can also use other interrupts, see section
 * "Optional MCU Description" below, or you can connect D- to the interrupt, as
 * it is required if you use the USB_COUNT_SOF feature. If you use D- for the
 * interrupt, the USB interrupt will also be triggered at Start-Of-Frame
 * markers every millisecond.]
 */
#define USB_CFG_CLOCK_KHZ       (F_CPU/1000)
/* Clock rate of the AVR in kHz. Legal values are 12000, 12800, 15000, 16000,
 * 16500, 18000 and 20000. The 12.8 MHz and 16.5 MHz versions of the code
 * require no crystal, they tolerate +/- 1% deviation from the nominal
 * frequency. All other rates require a precision of 2000 ppm and thus a
 * crystal!
 * Since F_CPU should be defined to your actual clock rate anyway, you should
 * not need to modify this setting.
 */
#define USB_CFG_CHECK_CRC       0
/* Define this to 1 if you want that the driver checks integrity of incoming
 * data packets (CRC checks). CRC checks cost quite a bit of code size and are
 * currently only available for 18 MHz crystal clock. You must choose
 * USB_CFG_CLOCK_KHZ = 18000 if you enable this option.
 */

/* ----------------------- Optional Hardware Config ------------------------ */

#define USB_CFG_PULLUP_IOPORTNAME   D
/* If you connect the 1.5k pullup resistor from D- to a port pin instead of
 * V+, you can connect and disconnect the device from firmware by calling
 * the macros usbDeviceConnect() and usbDeviceDisconnect() (see usbdrv.h).
 * This constant defines the port on which the pullup resistor is connected.
 */
#define USB_CFG_PULLUP_BIT          6
/* This constant defines the bit number in USB_CFG_PULLUP_IOPORT (defined
 * above) where the 1.5k pullup resistor is connected. See description
 * above for details.
 */

/* --------------------------- Functional Range ---------------------------- */
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

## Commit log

2022-12-03 Configuration and a blinking LED!
2022-12-04 Squashed 'v-usb/' content from commit 02a5d29
    git-subtree-dir: v-usb
    git-subtree-split: 02a5d29642149a4159da735285b952c4d0367c9b
    [tiny45-rc.sch, with-series-diodes.sch, with-vreg.sch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]
2022-12-07 Add '-e' flag to upload flags.
    From the avrdude docs: "Causes a chip erase to be executed. This will reset the contents of the flash ROM and EEPROM to the value `0xff', and clear all lock bits. Except for ATxmega devices which can use page erase, it is basically a
    prerequisite command before the flash ROM can be reprogrammed again. The only exception would be if the new contents would exclusively cause bits to be programmed from the value `1' to `0'."
2022-12-15 Can control a Switch!
2022-12-15 A little cleanup. Print update radar on LCD.
2022-12-15 Higher bandwidth for IN interrupts (to device) than for OUT interrupts (from devices). Gets update rate form ~15fps to ~65fps.
2022-12-17 Deal with HALTs sent to us on the OUT endpoint. A lot of cleanup. Switch to serial for debugging output.
2022-12-17 A little bit more clearnup and commentary. Handle 0x21 explicitly (but just return success!) - the Switch seemed to be sending these a lot and this quietens it down...
2022-12-25 V-USB working with 12.8MHz calibration. Data pin connections changed in V-USB configuration, and calibration routines included. main.cpp updated.
2022-12-28 Working Dual Shock to Switch conversion! Needs cleaning up and making more friendly (e.g. make analog mode be entered automatically).
2022-12-29 A little cleanup. Switch off USB_CFG_HAVE_FLOWCONTROL.
2022-12-31 Work on hang error. Turns out it might all just be because of the timing being off because of the serial output!?
    The response queueing I tried to implement probably violates the USB spec. Section 5.5.5 says:
    If a Setup transaction is received by an endpoint before a previously initiated control transfer is completed, the device must abort the current transfer/operation and handle the new control Setup transaction. A Setup transaction should not normally be sent before the completion of a previous control transfer. However, if a transfer is aborted, for example, due to errors on the bus, the host can send the next Setup transaction prematurely from the endpoint’s perspective.
    [main.cpp, usbconfig.h]
2022-12-31 Revert "Work on hang error. Turns out it might all just be because of the timing being off because of the serial output!?"
    This reverts commit e4f6621e0c4e36e6312164fe7e86283fce740181.
    [main.cpp, usbconfig.h]
2022-12-31 Better debug routines, and more verbose errors. We really need to run with no sertial printing now, especially at 12.8MHz, so the debug information is mostly off.
    [main.cpp]
2022-12-31 Pretend to habndle the "Set NFC/IR MCU state" UART call. This seems to be set any time a controller is selected in the Switch's "press the left and right shoulders" interface.
2023-01-02 A lot of changes. All sending now in one loop. Prints the elapsed SOF count for each loop, and it's really strance! On the internal connector, there are very often 1, and sometimes up to 3 sofs betwe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
2023-01-02 A lot of debugging changes. Naming changes. Don't always sent 64-byte packets! We can signify the end of a packet by sending a non-8-byte packet. There's still something weird going on with UART repl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
2023-01-09 Switch to using 16MHz crystal. Extra SOFs (i.e. at more than a 1MHz rate) seem to be making the self-calibration unstable enough to affect USB communication.
2023-01-09 Fix some UART responses, notably 0x21 "Set NFC/IR MCU config". Cleanup (boolean -> bool) and some performance improvements. Add some debug logs.
    [main.cpp]
2023-01-11 Fake USB HID controller that simulates 16 buttons and two analog sticks.
2023-04-08 Controlling a Nintendo Switch. For now, just alternately presses left and right on the dpad as a proof of concept.
2023-05-01 Implement resetting of reception on endpoint 1 on HALT state.
    [main.cpp, usbconfig.h]
2023-05-01 Switch to a 16MHz crystal for the clock. SOF debug output on PORTC bit 0.
2023-05-01 Instrument interrupt routines to output more debug information on PORTC. - Bit 0 is toggled when V-USB detects a SOF keep-alive pulse. - Bit 1 is set while V-USB is in its interrupt routine (i.e. pro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
2023-05-01 Switch off interrupts during MiniCore's (The Arduino framework) Timer0 intrerrupt routine, and switch back to using the inernal oscilator.
2023-05-05 Switch to using a serial bootloader.
    The new 'ATmega8Bootloader' environment contains the correct settings for setting up the bootloader. Put an ATMega8A in an ISP programmer then:
    > pio run -e ATmega8Bootloader -t bootloader
    Then connect a USB serial convertor to it, with a 0.1uf cap between DTR and the (pulled-up) ground connection, and the usual upload command will upload to it:
    > pio run -t upload
2023-05-06 Talk with a Dual Shock, and correctly translate to Switch reports.
    [main.cpp]
2023-05-07 Dead zone was far too small. Forgot to square the radius when implementing the circular dead zone!
    [main.cpp]
2023-05-08 Move DATA+ to pin 6 (PD4). Move the USB D- pull-up to be connected to pin 11 (PD5) to allow 'real' usbDeviceConnect() and usbDeviceDisconnect() (see usbconfig.h).
2023-05-10 Automatically switch the Dual Shock into analog mode, and treat presses of the 'ANALOG' button as home button presses.
2023-05-15 Remove unused (and wrong!) debug macro.
    [main.cpp]
2023-05-16 Change fuse settings for a 512 byte (256 word) bootloader, instead of a 512 word one.
2023-05-16 Change D- pull-up to go to PD5 (pin 11) because it fits on the breadboard better.
2023-05-16 Working over USB suspend. Of note:
    - New basic serial output routines to use instead of the Arduino ones. They are interrupt-free. I was finding that USB communication was
    becoming unreliable with serial debugging on. I believe the cause was MiniCore's use of the USB transmission interrupt.
    - Turns out the reportreception routine can use teh usual USB mechanism to know when reports are done (short packet or full length received), but I needed to increase the interrupt frequency for the OUT interrupt to get it to work. This has also greatly decreased the HALT
    /Stalls.
    - A few other reliability changes in usbFunctionWriteOutOrAbandon that were necessary for the controller to work after wake.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
    [main.cpp]
2023-05-17 Expunge the last remnants of the Arduino framework by replacing the timing routines with a very simple Timer0 driven replacement.
    [main.cpp]
2023-05-17 USB resume doesn't seem to work on Switch :-(
    [main.cpp]
2023-05-17 Power save mode on USB suspend.
2023-05-17 Power measurements on breadboard.
2023-05-17 Move timer routined to their own file.
2023-05-18 Comment corrections and some code reordering for clarity.
    [main.cpp]
2023-05-20 Rumble support! Juist uses the max ampliture to drive the big motor at the moment. Better debug output.
2023-05-23 Rumble fully decoded. Switched to a new packed strings format for debug strings to save program space.
2023-06-01 Better Dual Shock error handling.
    [main.cpp]
2023-06-02 Improved error checking added recently broke the ANALOG -> Home Button mapping.
    [main.cpp]
2023-06-02 Add KiCad project - schematic and PCB.
    [SwitchDualShockAdapter.kicad_pcb, SwitchDualShockAdapter.kicad_sch]
2023-06-13 Flip serial header to more intuitive orientation. Fix the debug LED to be in the correct orientation.
    [SwitchDualShockAdapter.kicad_pcb]
2023-06-13 Use both motors for all rumble if possible. Add a default OSCCAL for ATmega88.
2023-06-13 Switch the debug LED on immediately when a USB connection is detected.
2023-08-29 Bump version number on PCB.
    [SwitchDualShockAdapter.kicad_pcb]
2024-11-20 Header guards, move debug print declarations fo serial.h.
2024-11-20 Split SPI memory into seperate file.
2024-11-22 Allow the Switch to write calibration data to the ATMega's EEPROM. Comment some of the SPI data.
2024-11-26 Instead of deadzoning on the adapter, transmit the dead zone to the Switch and allow it to do deadzoning. Check the EEPROM for a magic number, and clear it if it's not found - allows us to clear the 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
2025-11-26 Generate MAC at compile time, so that every the switch can use multiple adapters simultaneously.
